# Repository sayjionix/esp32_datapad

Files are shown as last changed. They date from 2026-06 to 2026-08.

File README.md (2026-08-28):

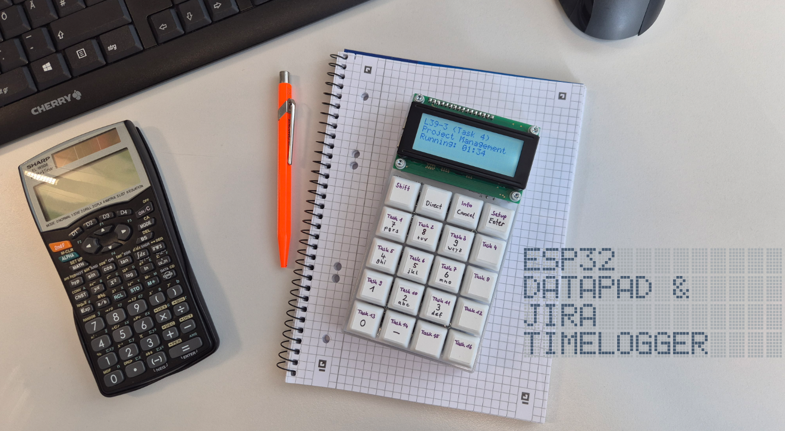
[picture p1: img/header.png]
Header


# ESP32 Datapad & Jira Timelogger Introduction
The __ESP32 Datapad & Jira Timelogger__ is a handheld ESP32-based keypad with 20 keys, a 20x4 character LCD display and a provision for operating from a single 3,7V LiPo cell. While the __Datapad__ hardware can generally be used for multiple purposes and provides a universal hardware development platform, the __timelogger__ firmware specifically allows tracking and logging time to [__Jira__](https://www.atlassian.com/software/jira).

The main features are:
* Connect the Datapad with your Atlassian Jira account using the REST API
* Map up to 16 favorite Jira tasks to the physical keys of the Datapad
* Tap a key once to start logging your time, tap again to stop logging and transfer the time to Jira
* Seamlessly switch over from logging on one task to another
* Manually enter spent time to book to your task
* Supports configuration of 2 WiFis to use the Datapad at two locations, e.g. at home and at workplace
* NTP-based time synchronization
* Use the Datapad as a development platform for your own keypad projects

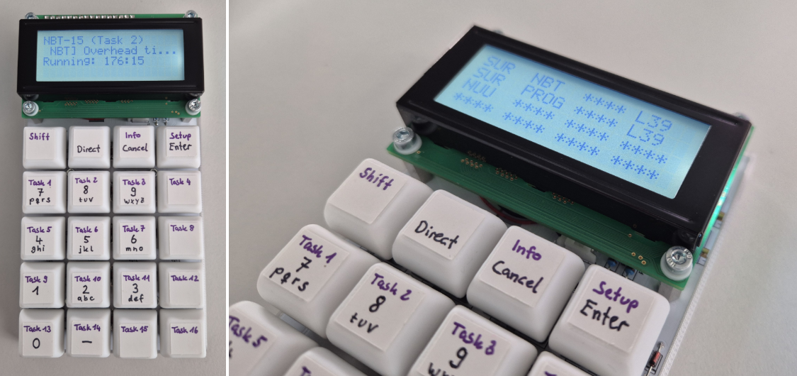
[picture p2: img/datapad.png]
datapad


# Build Instructions
Build your own Datapad! It's fun! :)

## BOM
The following table provides a BOM with Mouser and Reichelt part numbers.

| Part | Pcs | Type / Value | Mouser PN | Reichelt PN |
|---|:---:|---|---|---|
| | 1 | LCD Display 20x4 | 763-0420AZFSWGBW33V3 | |
| | 1 | Olimex ESP32-S3-DevKit-Lipo | 909-ESP32S3DEVKITLIP | |
| SW1-SW20 | 20  | Cherry MX Switch | 540-MX2A-E1NW | CHERRY MX2A-E1NW |
| D1-D20 | 20  | Diode 1N4148 | 512-1N4148 | 1N 4148 |
| Q1 | 1 | Transistor NPN BC548 | 637-BC548B | BC 548C |
| RV1 | 1 | Trim Poti 10k flat | | 64P-10K |
| RV2 | 1 | Trim Poti 2k flat | | 64P-2,0K |
| J1 | 1 | JST PH2P Socket | | JST PH2P ST90 |
| J2 | 1 | Pin Socket 1x16, 2,54mm, THT | 855-M20-7821646 | |
| | 1 | Pin Header 1x16, 2,54mm, THT | | |
| | 2 | Pin Header 1x22, 2,54mm, THT | | |
| R3 | 1 | Resistor 1/4W, 27k | | |
| R4 | 1 | Resistor 1/4W, 0R | | |
| SW21 | 1 | On-Off Switch | 611-OS102011MA1QN1 | |
| | 1 | LiPo Battery 3,7V, >= 100mAh | | |
| | 4 | 11mm Hexagonal Spacer or similar | | |

## Ordering and populating the PCB
The PCB can be ordered at any PCB manufacturer, such as [JLCPCB](https://jlcpcb.com/) or [PCBWay](https://www.pcbway.com/). In the [pcb/Datapad/fab/](pcb/Datapad/fab/) directory, there is a ZIP file with the Gerber and drill files, that can be used as-is to upload it to the manufacturer. For most manufacturers, you can likely leave all order options with their default values.

Soldering the components to the PCB should be simple, as the project only uses through-hole components. A generic tip is, to start with the small and flat parts first, such as the diodes and resistors, and then progress with the more bulky parts, such as the Cherry MX switches.

Solder the two 1x22 pin headers to the bottom of the Olimex ESP32 board and solder the 1x16 pin header to the bottom of the LCD display.

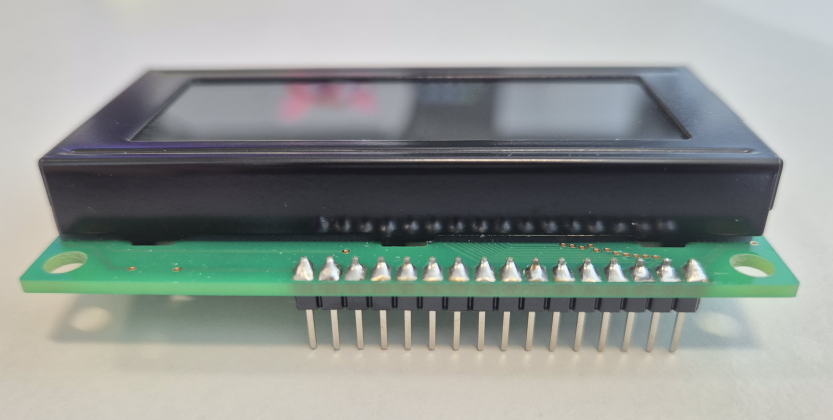
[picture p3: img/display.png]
display


It is recommended to solder the ESP32 with the attached pin headers to the main PCB as flush as possible to have enough clearance for the LCD display. Also, solder the ESP32 to the main PCB as one of the last steps. This way, you don't "lose" the ESP32 board in case any other step of the soldering goes wrong.

To power the ESP32 board from battery, solder a cable between the JST connector on the board and the Datapad PCB. Attach the battery with it's connector to the socket on the Datapad PCB.

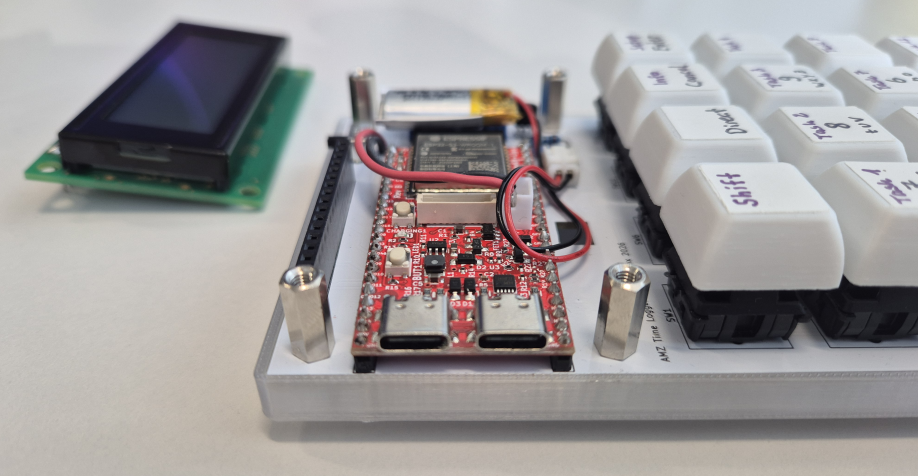
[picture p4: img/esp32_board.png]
esp32_board


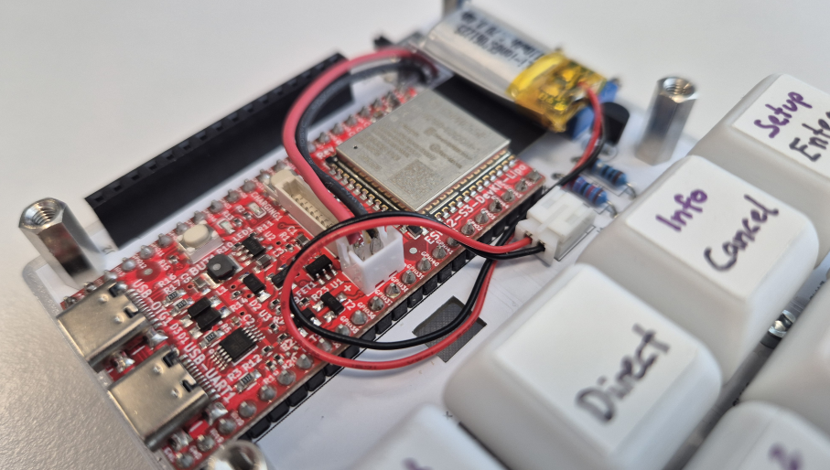
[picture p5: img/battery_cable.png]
battery_cable


## Programming the ESP32
This project is built and optimized using the PlatformIO ecosystem.

1. Download and install [VS Code](https://code.visualstudio.com/).
2. Install the PlatformIO IDE module directly from the VS Code Extensions Marketplace.
3. Connect the ESP32 board up to your PC with the right-side USB-C connector (when looking to the front of the USB ports. Labeled "USB-UART1").
4. Access the PlatformIO sidebar menu (represented by the Ant icon on the left panel grid) and open the timelogger project in the folder that contains the _platformio.ini_
5. Click the "Upload" action button (represented by the right-facing horizontal arrow icon along the bottom window status bar).
6. Wait for the code to be compiled and uploaded to the ESP32 via it's serial bootloader.

## 3D-printed Parts
There are *.stl files available in the [mechanical/](mechanical/) directory for two different variants of housings.

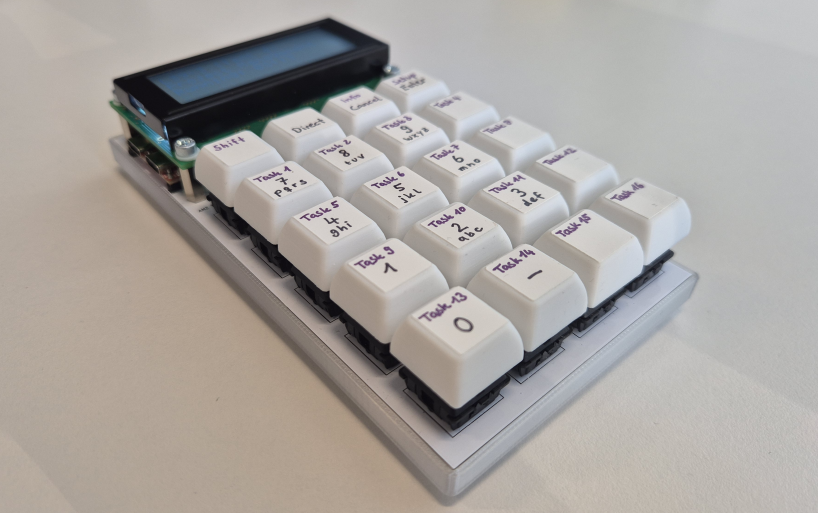
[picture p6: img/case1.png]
case1


For the Cherry MX Keycaps, the following free online model is recommended. However, any Cherry MX compatible keycaps can be used.<br>
https://makerworld.com/de/models/132469-xda-style-keycaps-blank#profileId-143606

# Operating Manual
## Keypad Layout
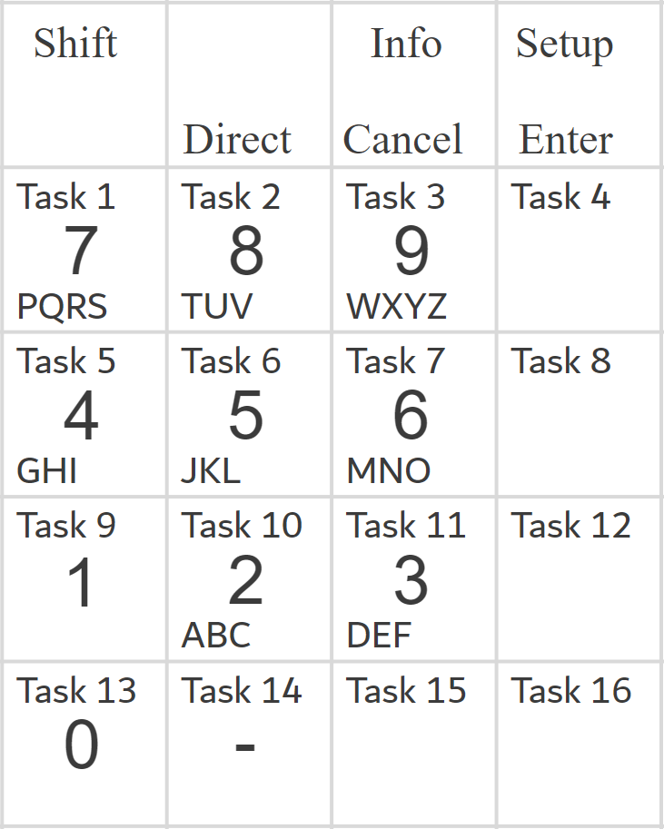
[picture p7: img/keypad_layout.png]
keypad_layout


## Energy Saving
After 60 seconds of inactivity, the Datapad will turn off the LCD display and backlight and it will bring the ESP32 into light sleep mode. Any running timers will keep on running in the background. To wake the Datapad up again, simply press any key on the keypad. This keypress will not trigger any action other than waking up.

## Display settings
Use the two potentiometers to adjust display contrast and backlight intensity.

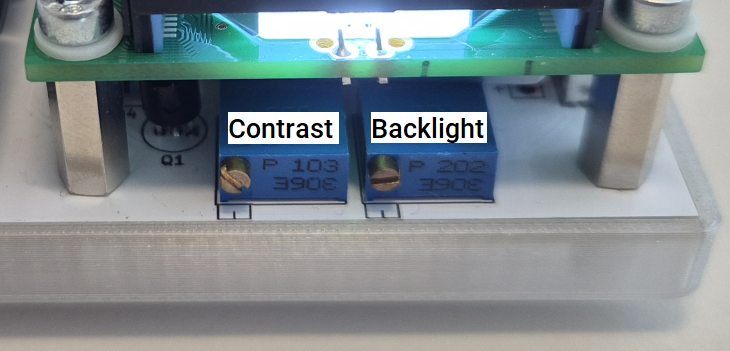
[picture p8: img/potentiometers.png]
potentiometers


## Battery operation
The On/Off switch on the top of the Datapad connects/disconnects the battery from the circuit. That means:

* to charge the battery from USB, make sure the On/Off switch is set to "On".
* the Datapad will be powered independently of the On/Off switch, once any of the two USB-C ports is connected to a power source.

## Base configuration
The basic configuration of the Datapad is performed via a serial terminal connection to your PC. You can use the same USB-C connection that you used for programming the ESP32 board and either utilize PlatformIO's Serial Monitor feature or any other serial terminal program of your choice. The serial setting are 115200baud, 8N1.

The basic configuration via the serial terminal includes:
1. WiFi 1 Name (SSID)
2. WiFi 1 Password
3. WiFi 2 Name (SSID)
4. WiFi 2 Password
5. Jira-Host
6. Base64 Credentials
7. Max Timer Duration

If the Datapad is started the first time and there is no configuration yet, it will prompt you to connect to your PC. The firmware can not start without the basic setup and having at least WiFi 1 configured and the Jira-Host and the Base64 Credentials set.

You can re-enter the basic configuration again at any time by pressing and holding the _SHIFT_ key + _ENTER_ key, while turning on the Datapad.

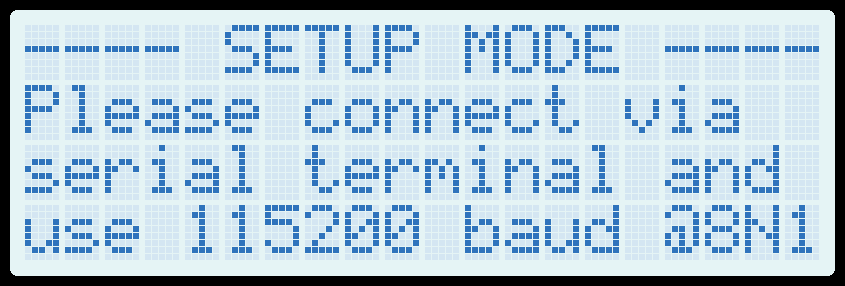
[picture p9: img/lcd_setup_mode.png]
lcd_setup_mode


Troubleshooting: If you don't see any output in the terminal, try sending anything (except a number between 1-8) to the Datapad. The firmware will reject this as an invalid choice for the main menu and re-render the main menu.

### Create your base64 credentials from your Jira API Token
A base64 representation of your Jira API token is required to access Jira's REST API. To get this, you have to perform the following steps:

1. Generate an API token for Jira using your Atlassian Account. Go to your account settings -> Security -> API Token.
2. Build a string of the form useremail:api_token.
3. BASE64 encode the string.

   Linux/Unix/MacOS:
   ```
   echo -n "user@example.com:api_token_string" | base64
   ```

   Windows 7 and later, using Microsoft Powershell:
   ```
   $Text = ‘user@example.com:api_token_string’
   $Bytes = [System.Text.Encoding]::UTF8.GetBytes($Text)
   $EncodedText = [Convert]::ToBase64String($Bytes)
   $EncodedText
   ```
4. Make sure that your resulting base64 string doesn't contain any unwanted carriage returns or other whitespace characters when you copy them to your Datapad configuration via the terminal. Unwanted whitespace characters are a common reason why the Jira login does not work later on. It can be easily checked by pasting the resulting base64 string into a text editor that can show whitespace characters, such as notepad++.

## Jira task mapping
If the Datapad starts with a valid configuration, it will show a 4x4 matrix of your 16 favorite Jira IDs on the LCD display (each Jira ID is consisting of the alphanumeric Jira key, followed by an unique number, e.g. "MGMT-2"). This 4x4 matrix corresponds to the lower 4x4 segment of the physical keypad.

If no Jira IDs have been mapped yet, each cell of the matrix will show "****".<br>
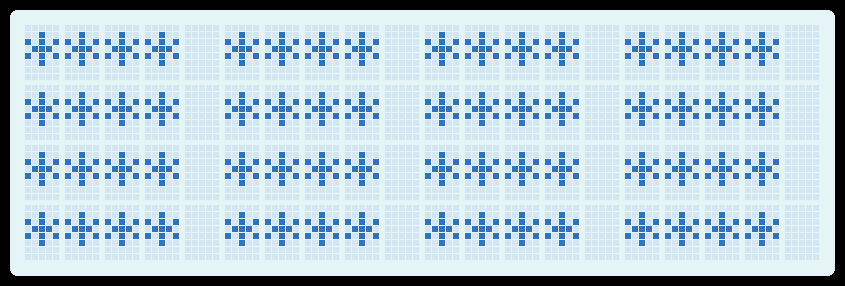
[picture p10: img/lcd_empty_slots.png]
lcd_empty_slots


Once Jira IDs have been mapped to the 4x4 matrix, the Datapad will periodically cycle through indicating the Jira key and the unique identifier at the given cell on the LCD display.<br>
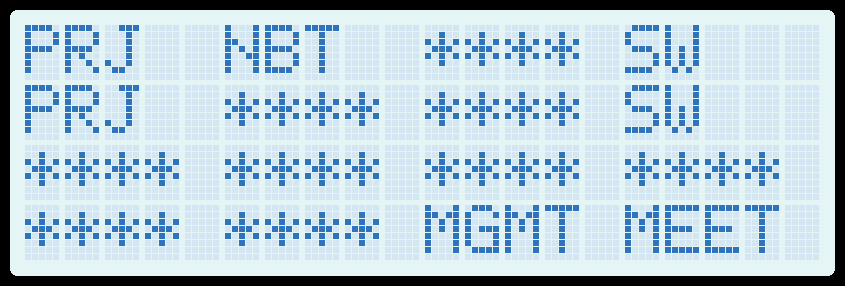
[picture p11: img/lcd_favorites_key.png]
lcd_favorites_key

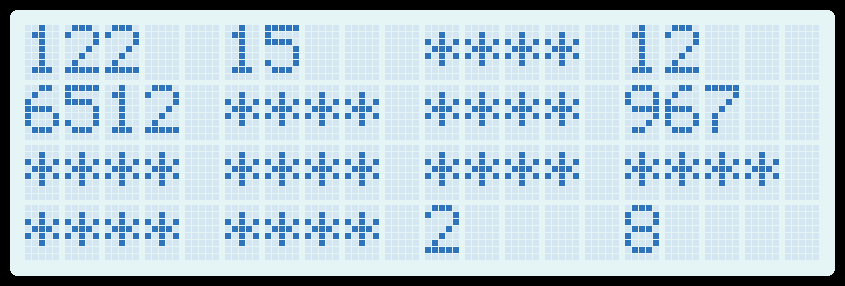
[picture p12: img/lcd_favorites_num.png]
lcd_favorites_num


### Map a Jira task ID to a physical key
To map a new Jira task to any of the free slots of your 4x4 matrix of favorites, simply press and hold the _SHIFT_ key and then press the key that corresponds to the slot you like to map. A dialog will show on the LCD display that prompts you for the Jira ID. The Jira ID can be entered using the T9-feature of the keypad. Each Jira ID is consisting of the alphanumeric Jira key, followed by an unique number, e.g. "MGMT-2".

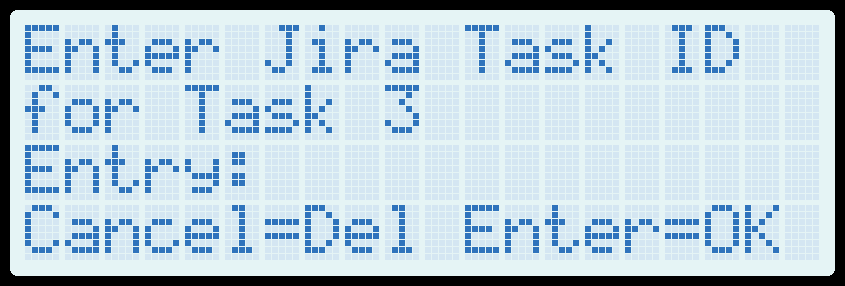
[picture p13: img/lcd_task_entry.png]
lcd_task_entry


To correct a typing mistake or to exit the dialog completely, simply press _CANCEL_ (repeatedly).
To conclude your entry and map the Jira ID, press _ENTER_. The Datapad will call the REST API to fetch information about the task, such as the task's name. If the task can not be found or there is any other issue with the connection to your Jira server, the mapping will be completed, calling the task "Unknown Task". 

### Remove a Jira task ID from a physical key
To remove a Jira task from the 4x4 matrix of favorites, simply press and hold the _CANCEL_ key before pressing the key of the task you like to remove. A confirmation dialoge will prompt you to either continue by pressing _ENTER_, or to cancel the removal by pressing _CANCEL_.

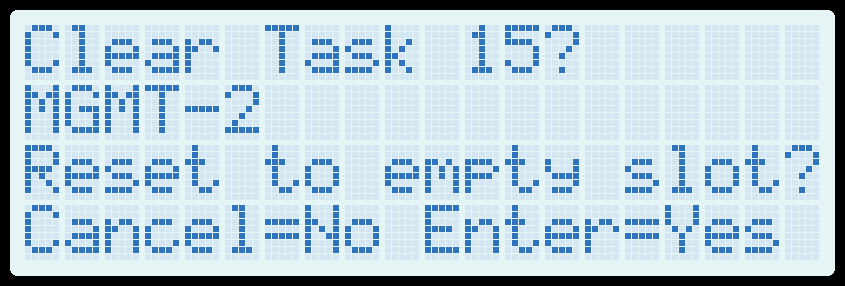
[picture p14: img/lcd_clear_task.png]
lcd_clear_task


Once the Jira task is removed, the slot becomes free again and is displayed as "****".

### Show task name
When mapping a Jira task to one of the slots of the 4x4 matrix, the Datapad will try to obtain the task's name via the Jira REST API. To display the name of a task in your 4x4 matrix, simply press and hold the _ENTER_ key before pressing the key of the task you like to show. This can be helpful when you are unsure to recognize the right task just judging from the Jira ID.

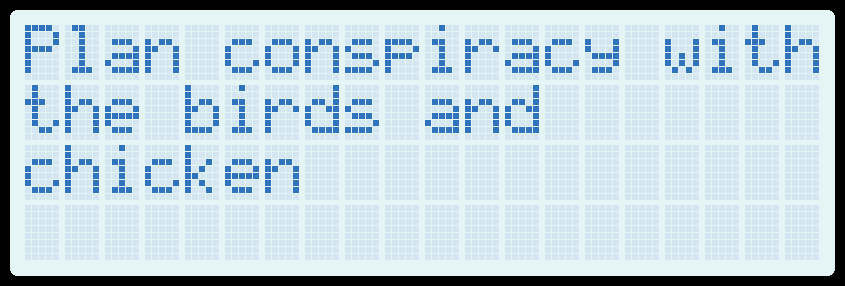
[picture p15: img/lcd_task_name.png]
lcd_task_name


## Log time
There are two ways to log time to your Jira tasks.

### Automatic timer mode
A worklog timer can be started for any of the Jira tasks from the 4x4 matrix of favorites by simply pressing the key that corresponds to the task you like to log. Once the timer has started, the LCD display switches to an indication of the running timer. To stop a running timer, press the according task key again. A dialog will prompt you to confirm whether you would like to log the recorded timer to Jira. Press the _ENTER_ key once you are ready to log the time. The Datapad will then transmit the time to Jira via the REST API and automatically calculate the starting time of the activity based on the recorded minutes. Press _CANCEL_ to discard the recorded time.

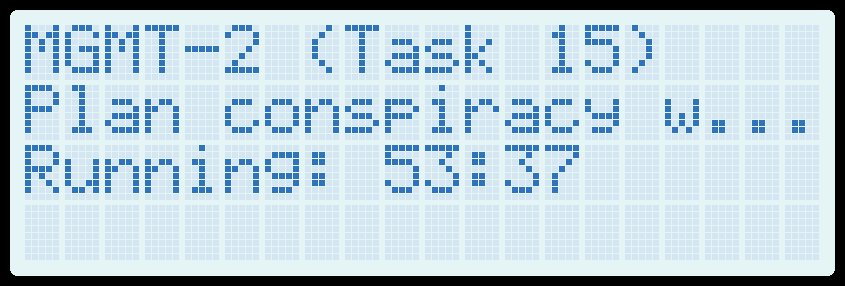
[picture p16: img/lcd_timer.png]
lcd_timer


If you start a timer in parallel on a different Jira task, the Datapad will automatically stop the previously running timer and prompt you, whether to keep or discard the recording of the previous timer. It will then start the new timer.

Timers can only be started on non-empty slots.

### Direct entry
Time can also be entered directly to be logged to a certain Jira task. This is helpful if you forgot to start the timer before you started working on your activity and you would like to restrospecively log the time.

Press and hold _DIRECT_ and then press the key that corresponds to the task you like to log to. A dialog will prompt you to enter the time in minutes using the numeric keys. Press the _CANCEL_ key to correct your entry or to completely cancel the direct time entry. Press the _ENTER_ key once you are ready to log the time. The Datapad will then transmit the time to Jira via the REST API and automatically calculate the starting time of the activity based on the entered minutes.

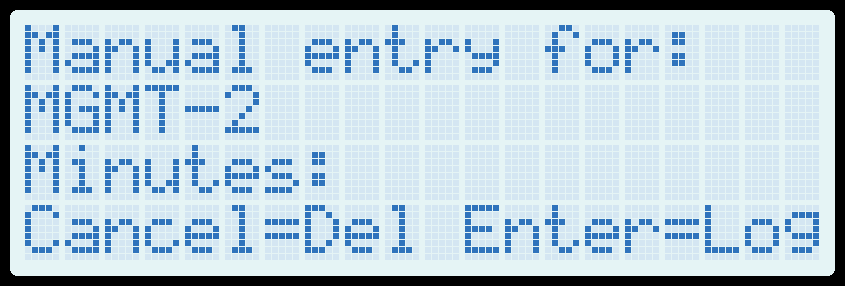
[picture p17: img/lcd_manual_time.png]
lcd_manual_time


## Information Display
When pressing the _SHIFT_ and _INFO_ keys simultaneously while being in the 4x4 overview, the LCD display will show:
* Firmware version
* Battery voltage (when running from battery) or "USB connected" (when being powered from USB)
* Actual time and date. Time and date will be fetched via NTP every 3 hours. This is to compensate for the poor crystal accuracy of the ESP32 board and the clock drift that comes as a result

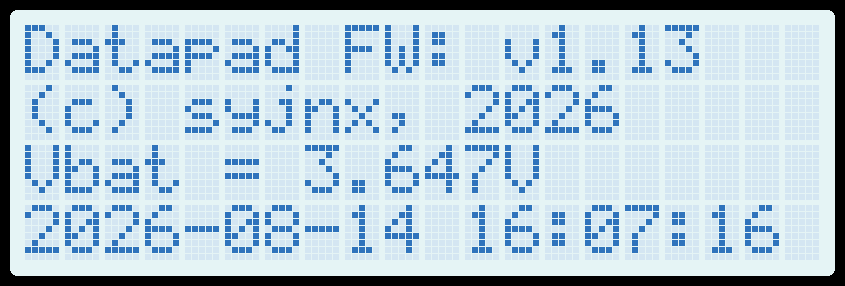
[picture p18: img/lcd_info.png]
lcd_info


Press _CANCEL_ or _ENTER_ to return.

# Hardware Changelog
**v1.0, 31.05.2026:** First fab release of PCB.

# License
The Datapad Timelogger is released under the GNU GPLv3.<br>
Please refer to the [LICENSE](./LICENSE) file for more information.

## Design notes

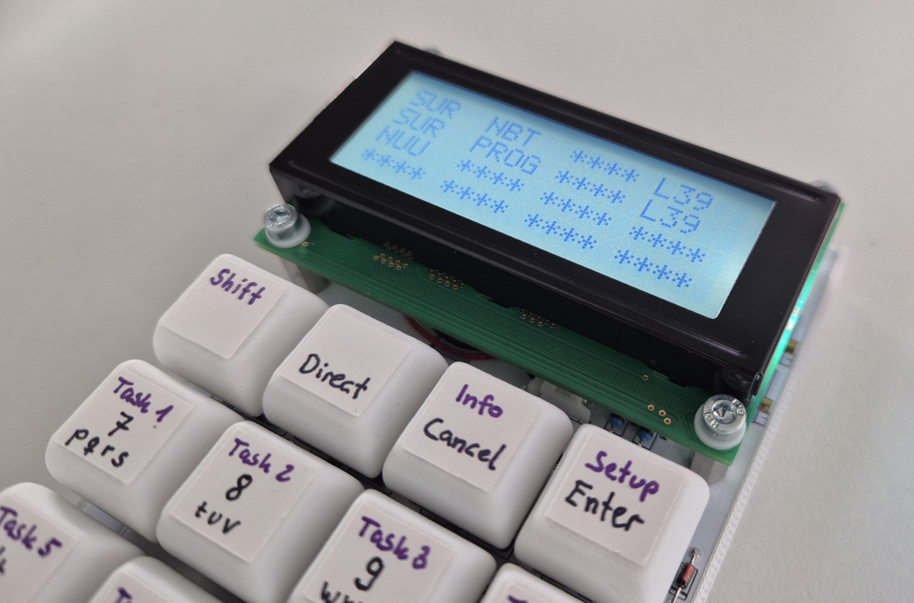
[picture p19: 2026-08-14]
img/datapad_2.png

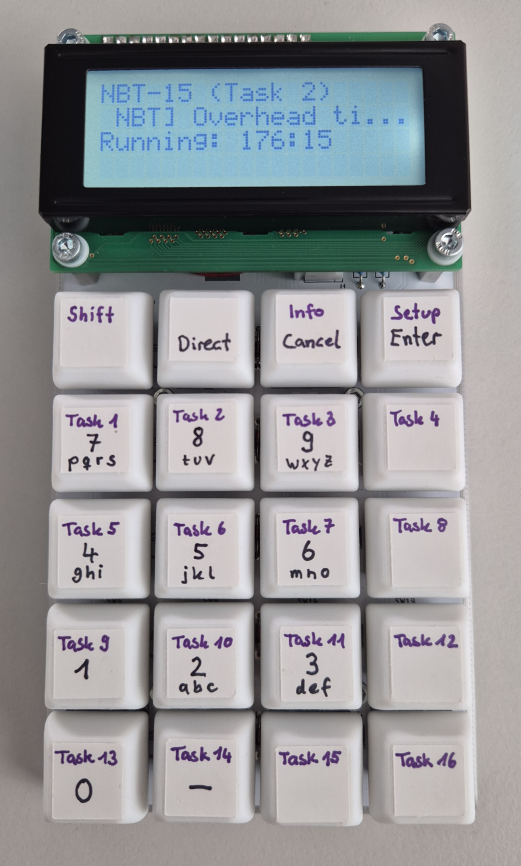
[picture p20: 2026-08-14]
img/datapad_1.png

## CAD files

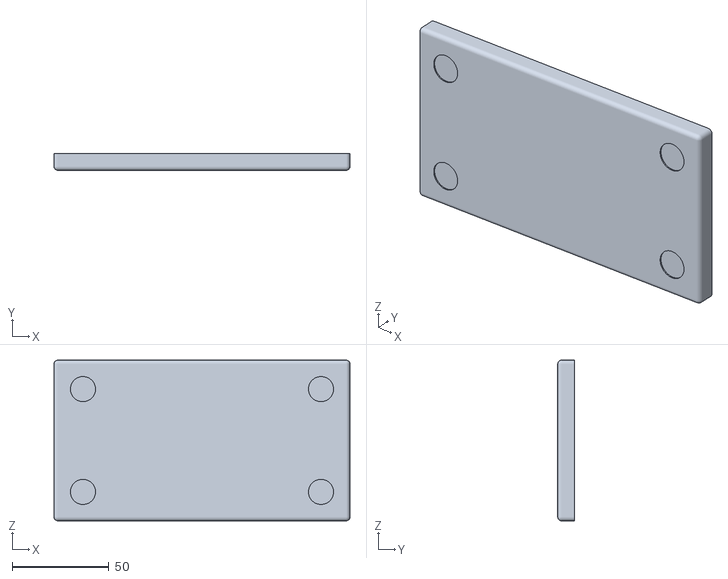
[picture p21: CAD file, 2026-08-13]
mechanical/Datapad_Case_v2.stl
153.2 x 8.60 x 83.2

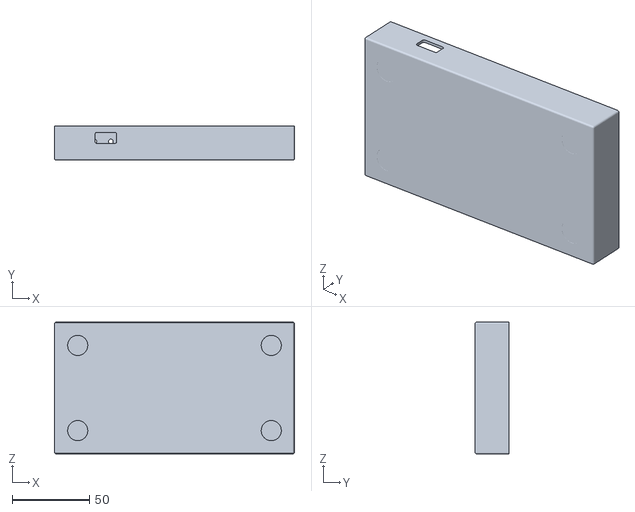
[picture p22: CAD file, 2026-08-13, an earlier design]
mechanical/Datapad_Case_v1.stl
155.0 x 22.0 x 85.0

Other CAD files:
mechanical/Datapad_Case_v1.ipt
mechanical/Datapad_Case_v2.ipt

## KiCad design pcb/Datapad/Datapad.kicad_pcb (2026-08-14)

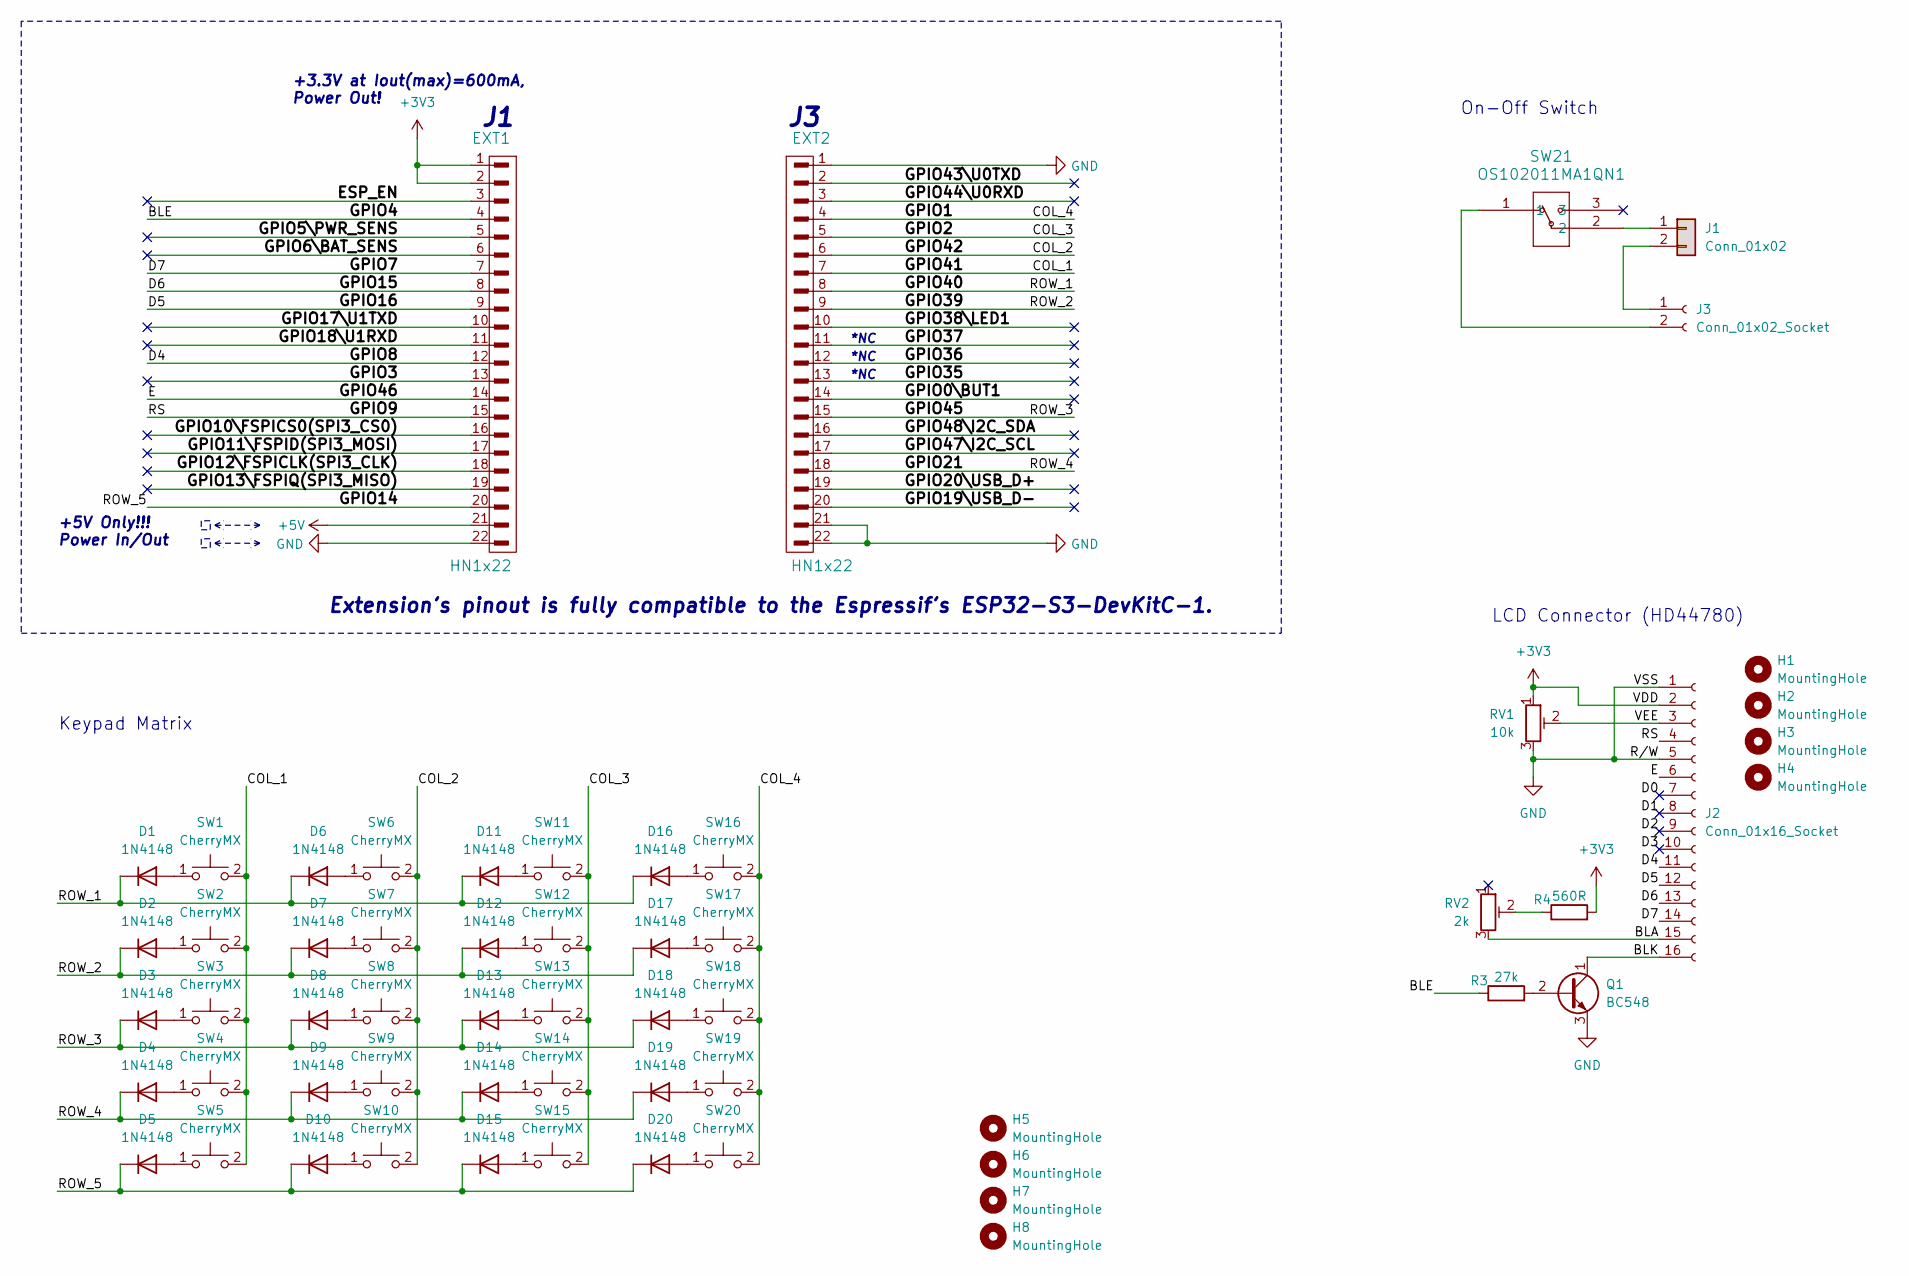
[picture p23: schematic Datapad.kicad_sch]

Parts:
D1, D2, D3, D4, D5, D6, D7, D8, D9, D10, D11, D12, D13, D14, D15, D16, D17, D18, D19, D20: 1N4148; D_DO-35_SOD27_P7.62mm_Horizontal
EXT1, EXT2: HN1x22; PinSocket_1x22_P2.54mm_Vertical
H1, H2, H3, H4: MountingHole; MountingHole_4mm
H5, H6, H7, H8: MountingHole; MountingHole_2.7mm
J1: Conn_01x02; JST_PH_S2B-PH-K_1x02_P2.00mm_Horizontal
J2: Conn_01x16_Socket; PinSocket_1x16_P2.54mm_Vertical
J3: Conn_01x02_Socket; PinSocket_1x02_P2.54mm_Vertical
Q1: BC548; TO-92_Inline
R3: 27k; R_Axial_DIN0207_L6.3mm_D2.5mm_P10.16mm_Horizontal
R4: 560R; R_Axial_DIN0207_L6.3mm_D2.5mm_P10.16mm_Horizontal
RV1: 10k; Potentiometer_Bourns_3296P_Horizontal
RV2: 2k; Potentiometer_Bourns_3296P_Horizontal
SW1, SW2, SW3, SW4, SW5, SW6, SW7, SW8, SW9, SW10, SW11, SW12, SW13, SW14, SW15, SW16, SW17, SW18, SW19, SW20: CherryMX; SW_Cherry_MX_1.00u_PCB
SW21: OS102011MA1QN1; OS102011MA1QN1_CNK

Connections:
+3V3: EXT1.1, EXT1.2, J2.2, R4.2, RV1.1
+5V: EXT1.21
/BLA: J2.15, RV2.3
/BLE: EXT1.4, R3.1
/BLK: J2.16, Q1.1 (C)
/COL_1: EXT2.7, SW1.2, SW2.2, SW3.2, SW4.2, SW5.2
/COL_2: EXT2.6, SW6.2, SW7.2, SW8.2, SW9.2, SW10.2
/COL_3: EXT2.5, SW11.2, SW12.2, SW13.2, SW14.2, SW15.2
/COL_4: EXT2.4, SW16.2, SW17.2, SW18.2, SW19.2, SW20.2
/D0: J2.7
/D1: J2.8
/D2: J2.9
/D3: J2.10
/D4: EXT1.12, J2.11
/D5: EXT1.9, J2.12
/D6: EXT1.8, J2.13
/D7: EXT1.7, J2.14
/E: EXT1.14, J2.6
/ESP_EN: EXT1.3
/GPIO0\BUT1: EXT2.14
/GPIO3: EXT1.13
/GPIO5\PWR_SENS: EXT1.5
/GPIO6\BAT_SENS: EXT1.6
/GPIO9: EXT1.15, J2.4
/GPIO10\FSPICS0(SPI3_CS0): EXT1.16
/GPIO11\FSPID(SPI3_MOSI): EXT1.17
/GPIO12\FSPICLK(SPI3_CLK): EXT1.18
/GPIO13\FSPIQ(SPI3_MISO): EXT1.19
/GPIO14: D5.1 (K), D10.1 (K), D15.1 (K), D20.1 (K), EXT1.20
/GPIO17\U1TXD: EXT1.10
/GPIO18\U1RXD: EXT1.11
/GPIO19\USB_D-: EXT2.20
/GPIO20\USB_D+: EXT2.19
/GPIO21: D4.1 (K), D9.1 (K), D14.1 (K), D19.1 (K), EXT2.18
/GPIO35: EXT2.13
/GPIO36: EXT2.12
/GPIO37: EXT2.11
/GPIO38\LED1: EXT2.10
/GPIO39: D2.1 (K), D7.1 (K), D12.1 (K), D17.1 (K), EXT2.9
/GPIO40: D1.1 (K), D6.1 (K), D11.1 (K), D16.1 (K), EXT2.8
/GPIO43\U0TXD: EXT2.2
/GPIO44\U0RXD: EXT2.3
/GPIO45: D3.1 (K), D8.1 (K), D13.1 (K), D18.1 (K), EXT2.15
/GPIO47\I2C_SCL: EXT2.17
/GPIO48\I2C_SDA: EXT2.16
/VEE: J2.3, RV1.2
GND: EXT1.22, EXT2.1, EXT2.21, EXT2.22, J2.1, J2.5, Q1.3 (E), RV1.3
unnamed: D1.2 (A), SW1.1
unnamed: D2.2 (A), SW2.1
unnamed: D3.2 (A), SW3.1
unnamed: D4.2 (A), SW4.1
unnamed: D5.2 (A), SW5.1
unnamed: D6.2 (A), SW6.1
unnamed: D7.2 (A), SW7.1
unnamed: D8.2 (A), SW8.1
unnamed: D9.2 (A), SW9.1
unnamed: D10.2 (A), SW10.1
unnamed: D11.2 (A), SW11.1
unnamed: D12.2 (A), SW12.1
unnamed: D13.2 (A), SW13.1
unnamed: D14.2 (A), SW14.1
unnamed: D15.2 (A), SW15.1
unnamed: D16.2 (A), SW16.1
unnamed: D17.2 (A), SW17.1
unnamed: D18.2 (A), SW18.1
unnamed: D19.2 (A), SW19.1
unnamed: D20.2 (A), SW20.1
unnamed: J1.1, SW21.2
unnamed: J1.2, J3.1
unnamed: J3.2, SW21.1
unnamed: Q1.2 (B), R3.2
unnamed: R4.1, RV2.2

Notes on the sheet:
+5V Only!!! Power In/Out
Keypad Matrix
+3.3V at Iout(max)=600mA, Power Out!
Extension's pinout is fully compatible to the Espressif's ESP32-S3-DevKitC-1.
*NC
On-Off Switch
LCD Connector (HD44780)

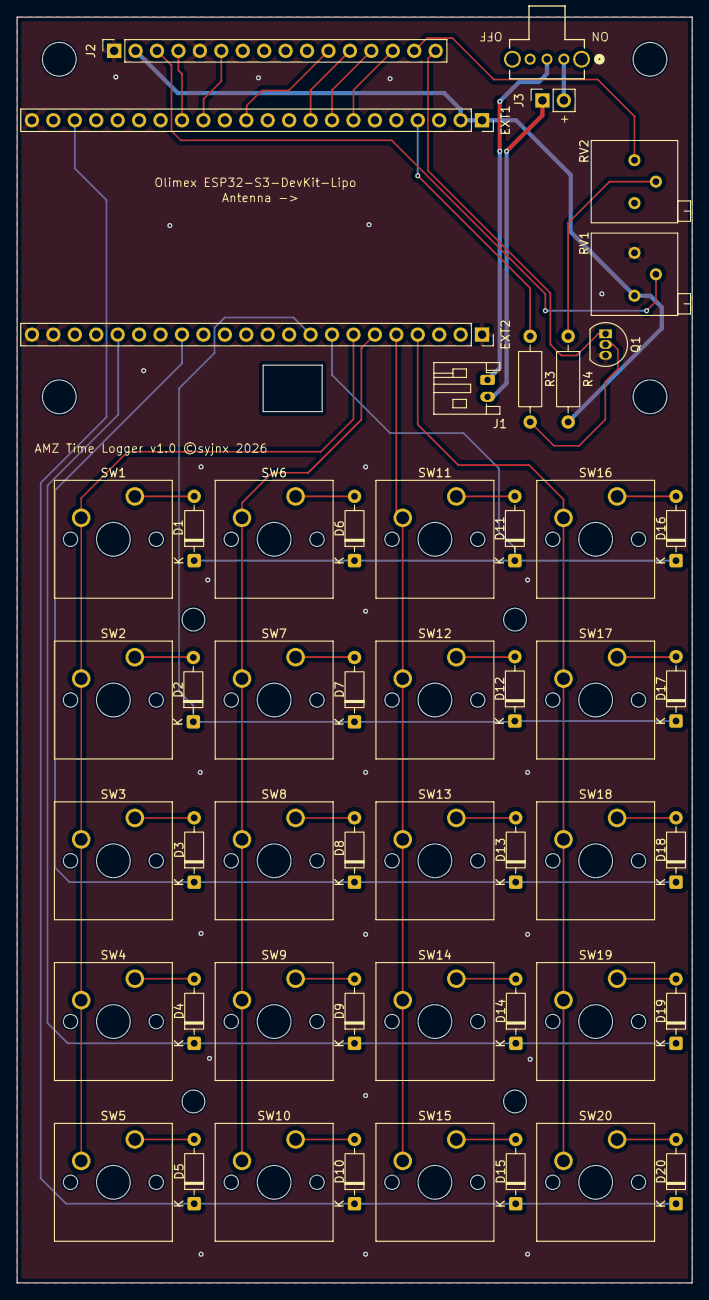
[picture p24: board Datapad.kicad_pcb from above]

Board: 2 copper layers, 80.0 x 150.0 mm, 59 parts (0 on the bottom side), 46 nets.

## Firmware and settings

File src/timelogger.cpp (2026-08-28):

/**************************************************************************************************/
/** @file      timelogger.cpp
 *  @copyright (C) 2026, sayjionix (syjnx), All Rights Reserved
 *             https://github.com/sayjionix/esp32_datapad
 *  @brief     Main program file of Jira timelogger firmware for the ESP32 Datapad
 *  @date      13.08.2026
 */
/**************************************************************************************************/

/*** Component includes ***/
/**************************************************************************************************/
#include <WiFi.h>
#include <HTTPClient.h>
#include <WiFiClientSecure.h>
#include <Keypad.h>
#include <Preferences.h>
#include <LiquidCrystal.h>
#include <ArduinoJson.h>
#include <time.h>

/*** Component local macro definitions ***/
/**************************************************************************************************/
// HD44780 LCD Pins: LiquidCrystal lcd(rs, en, d4, d5, d6, d7)
LiquidCrystal lcd(9, 46, 8, 16, 15, 7);
#define BACKLIGHT_PIN  4    // GPIO4
#define BAT_ADC_PIN    6    // GPIO6 (Battery)
#define PWR_ADC_PIN    5    // GPIO5 (External power)

#define ADC_RESOLUTION 4095.0
#define ADC_REF        3.3

// Correct ratios from schematic
#define BAT_DIVIDER_RATIO  4.1333
#define PWR_DIVIDER_RATIO  5.6808

// 5V through divider gives ~880mV at ADC, anything above 400mV means external power present
#define PWR_PRESENT_THRESHOLD 400

/*** Component local type declarations ***/
/**************************************************************************************************/

/*** Component exported data definitions ***/
/**************************************************************************************************/

/*** Component local data definitions ***/
/**************************************************************************************************/
Preferences preferences;
String VERSION = "v1.15";

// WiFi and Jira configuration variables
String ssid = "";
String password = "";
String ssid2 = "";
String password2 = "";
String jiraHost = ""; 
String base64Credentials = ""; 
unsigned long maxTimerHours = 10; // Default maximum tracking duration in hours

unsigned long lastActivityTime = 0;
const unsigned long displayTimeout = 60000; 
bool isDisplayOn = true;
bool displayNameToggle = true;
bool isShowingInfoPage = false; // Flag to block UI drawing while showing version info

// Variables for Task Name Inspector Feature
bool isShowingTaskInspector = false;
unsigned long taskInspectorStartTime = 0;
const unsigned long taskInspectorTimeout = 2000; // 2 seconds

unsigned long lastNTPSyncTime = 0;
const unsigned long ntpSyncInterval = 10800000; // 3 hours in milliseconds

// Keypad Definition (rows and cols are inverted here to match anti-ghosting diode polarity with library code)
const byte ROWS = 4; 
const byte COLS = 5; 
char hexaKeys[ROWS][COLS] = {
  {'S','7','4','1','0'},
  {'A','8','5','2','G'},
  {'B','9','6','3','H'},
  {'C','D','E','F','I'}
};
byte rowPins[ROWS] = {41, 42, 2, 1}; 
byte colPins[COLS] = {40, 39, 45, 21, 14};
int keyTaskMap[ROWS][COLS] = {
  {-1,0,4,8,12},
  {-1,1,5,9,13},
  {-1,2,6,10,14},
  {-1,3,7,11,15}
};

Keypad customKeypad = Keypad(makeKeymap(hexaKeys), rowPins, colPins, ROWS, COLS);

String taskMapping[20];
String taskNames[20];
unsigned long startTimes[20] = {0};
int activeTimerIndex = -1;

int configIndex = -1;
int manualTimeIndex = -1;
int confirmTrackingIndex = -1;
unsigned long confirmDurationMinutes = 0;
int nextTimerIndexToStart = -1;

// Variables for slot deletion
int deleteIndex = -1;
bool isShowingDeleteDialog = false;

String currentInput = "";
char lastT9Key = '\0';
int t9CycleIndex = 0;
unsigned long lastT9Time = 0;
const unsigned long t9Timeout = 1200;

const String t9Chars[11] = {
  "1", "ABC2", "DEF3", "GHI4", "JKL5", "MNO6", "PQRS7", "TUV8", "WXYZ9", "0", "-"
};

/*** Component local function declarations ***/
/**************************************************************************************************/
void resetDisplayTimeout();
void updateDefaultDisplay();
String readSerialLine();
void runSerialSetup();
String fetchTaskSummary(String issueKey);
void handleManualTimeInput(char key);
void handleT9Input(char key);
void handleTracking(int index);
void handleConfirmationInput(char key);
void handleDeletionInput(char key);
void logTimeToJira(const char* issueKey, unsigned long minutes);
void enterLowPowerMode();
bool connectToWiFiNetwork(String targetSsid, String targetPass, const char* label);
bool ensureWiFiConnected();
void showTaskNameMultiLine(String name);

// Read battery voltage
float readBatVoltage()
{
  uint32_t adcRaw = analogRead(BAT_ADC_PIN);

  float adcVoltage = (adcRaw / ADC_RESOLUTION) * ADC_REF;
  float realVoltage = adcVoltage * BAT_DIVIDER_RATIO;

  return realVoltage;
}

// Check for external power via USB
bool externalPowerPresent()
{
  uint32_t adcRaw = analogRead(PWR_ADC_PIN);
  float adcVoltage = (adcRaw / ADC_RESOLUTION) * ADC_REF;
  return (((uint16_t)(adcVoltage * 1000.0)) > PWR_PRESENT_THRESHOLD);
}

// Return the index of the keypad's key-to-task mapping
int getKeyIndex(char key)
{
  for (int i = 0; i < ROWS; i++) {
    for (int j = 0; j < COLS; j++) {
      if (hexaKeys[i][j] == key) {
        return keyTaskMap[i][j];
      }
    }
  }
  return -1;
}

// Map keypad keys to T9 layout indices
int getT9LayoutIndex(char key)
{
  if (key >= '1' && key <= '9') return key - '1';
  if (key == '0') return 9;
  if (key == 'G') return 10;
  return -1;
}

// Reset display sleep timer
void resetDisplayTimeout()
{
  lastActivityTime = millis();
}

// Splits and draws a string across 4 rows on the LCD
void showTaskNameMultiLine(String name)
{
  lcd.clear();
  int startIdx = 0;
  for (int row = 0; row < 4; row++) {
    if (startIdx >= name.length()) break;
    
    String line = name.substring(startIdx, startIdx + 20);
    
    // Simple word wrapping helper logic if within boundary limits
    if (startIdx + 20 < name.length() && line.lastIndexOf(' ') > 10) {
      int lastSpace = line.lastIndexOf(' ');
      line = line.substring(0, lastSpace);
      startIdx += lastSpace + 1;
    } else {
      startIdx += 20;
    }
    
    lcd.setCursor(0, row);
    lcd.print(line);
  }
}

// Render the current UI state to the LCD
void updateDefaultDisplay()
{
  // Block redraw requests if user is interacting with modal sub-pages or dialogs
  if (isShowingInfoPage || isShowingDeleteDialog || isShowingTaskInspector) return;

  lcd.clear();
  
  // There is an active timer running
  if(activeTimerIndex != -1)
  {
    // Show real task name (if available) and associated key
    lcd.setCursor(0, 0);
    String displayName = taskMapping[activeTimerIndex] + " (Task " + (activeTimerIndex+1) + ")";
    lcd.print(displayName);
    lcd.setCursor(0, 1);
    displayName = taskNames[activeTimerIndex];
    if (displayName.length() > 20) displayName = displayName.substring(0, 17) + "...";
    lcd.print(displayName);
  }
  // No active timer running -> show Jira ID overview matrix
  else
  {
    for(int line=0; line < 4; line++) {
      for (int j=0; j < 4; j++) {
        lcd.setCursor(j*5, line);
        String displayName = taskMapping[line*4+j];
        int dashidx = displayName.indexOf('-');

        // Toggle between Project Key and Issue Number display
        if(displayNameToggle) {
          displayName = displayName.substring(0, dashidx);
        }
        else {
          displayName = displayName.substring(dashidx+1, dashidx+7);
        }
        if (displayName.length() > 4) {
          displayName = displayName.substring(0, 4);
        }
        lcd.print(displayName);
      }
    }
  }
}

// Robustly read a line from serial interface filtering out both Carriage Return and Line Feed
String readSerialLine()
{
  String input = "";
  while (true) {
    if (Serial.available()) {
      char c = Serial.read();
      if (c == '\n' || c == '\r') {
        // If we hit a newline character and already have content, we finish reading
        if (input.length() > 0) {
          break;
        }
      } else {
        input += c;
      }
    }
    delay(5);
  }
  input.trim();
  return input;
}

// Interactive configuration wizard via hardware serial terminal
void runSerialSetup()
{
  lcd.clear();
  lcd.setCursor(0, 0); lcd.print("---- SETUP MODE ----");
  lcd.setCursor(0, 1); lcd.print("Please connect via  ");
  lcd.setCursor(0, 2); lcd.print("serial terminal and ");
  lcd.setCursor(0, 3); lcd.print("use 115200 baud @8N1");

  // Load existing values first so they are up to date in the menu
  ssid = preferences.getString("wifi_ssid", "");
  password = preferences.getString("wifi_pass", "");
  ssid2 = preferences.getString("wifi_ssid2", "");
  password2 = preferences.getString("wifi_pass2", "");
  jiraHost = preferences.getString("jira_host", "");
  base64Credentials = preferences.getString("jira_cred", "");
  maxTimerHours = preferences.getUInt("max_hours", 10);

  while (true) {
    Serial.println("\n==================================================");
    Serial.println("         CONFIGURATION OF TIME TRACKER            ");
    Serial.println("==================================================");
    Serial.print("1. WiFi 1 Name (SSID):       "); Serial.println(ssid == "" ? "[NOT SET]" : ssid);
    Serial.print("2. WiFi 1 Password:          "); Serial.println(password == "" ? "[NOT SET]" : "********");
    Serial.print("3. WiFi 2 Name (SSID):       "); Serial.println(ssid2 == "" ? "[NOT SET (OPTIONAL)]" : ssid2);
    Serial.print("4. WiFi 2 Password:          "); Serial.println(password2 == "" ? "[NOT SET]" : "********");
    Serial.print("5. Jira-Host:                "); Serial.println(jiraHost == "" ? "[NOT SET]" : jiraHost);
    Serial.print("6. Base64 Credentials:       "); Serial.println(base64Credentials == "" ? "[NOT SET]" : "[SAVED]");
    Serial.print("7. Max Timer Duration:       "); Serial.print(maxTimerHours); Serial.println(" Hours");
    Serial.println("--------------------------------------------------");
    Serial.println("8. Restart System");
    Serial.println("==================================================");
    Serial.print("Please select an option (1-8): ");

    String choice = readSerialLine();
    Serial.println(choice);

    if (choice == "1") {
      Serial.print("Enter new WiFi 1 Name (SSID): ");
      ssid = readSerialLine();
      Serial.println(ssid);
      preferences.putString("wifi_ssid", ssid);
      Serial.println("--> WiFi 1 Name updated in storage.");
    } 
    else if (choice == "2") {
      Serial.print("Enter new WiFi 1 Password: ");
      password = readSerialLine();
      Serial.println("********");
      preferences.putString("wifi_pass", password);
      Serial.println("--> WiFi 1 Password updated in storage.");
    } 
    else if (choice == "3") {
      Serial.print("Enter new WiFi 2 Name (SSID): ");
      ssid2 = readSerialLine();
      Serial.println(ssid2);
      preferences.putString("wifi_ssid2", ssid2);
      Serial.println("--> WiFi 2 Name updated in storage.");
    }
    else if (choice == "4") {
      Serial.print("Enter new WiFi 2 Password: ");
      password2 = readSerialLine();
      Serial.println("********");
      preferences.putString("wifi_pass2", password2);
      Serial.println("--> WiFi 2 Password updated in storage.");
    }
    else if (choice == "5") {
      Serial.print("Enter new Jira-Host (e.g. company.atlassian.net): ");
      jiraHost = readSerialLine();
      Serial.println(jiraHost);
      preferences.putString("jira_host", jiraHost);
      Serial.println("--> Jira-Host updated in storage.");
    } 
    else if (choice == "6") {
      Serial.print("Enter new Base64 Credentials: ");
      base64Credentials = readSerialLine();
      Serial.println("[SAVED]");
      preferences.putString("jira_cred", base64Credentials);
      Serial.println("--> Base64 Credentials updated in storage.");
    } 
    else if (choice == "7") {
      Serial.print("Enter max timer duration (in hours): ");
      String hrsInput = readSerialLine();
      long parsedHrs = hrsInput.toInt();
      if (parsedHrs > 0) {
        maxTimerHours = parsedHrs;
        Serial.print(maxTimerHours); Serial.println(" Hours");
        preferences.putUInt("max_hours", maxTimerHours);
        Serial.println("--> Max timer duration updated in storage.");
      } else {
        Serial.println("Invalid input! Must be a positive number.");
      }
    } 
    else if (choice == "8") {
      Serial.println("\n--> All settings successfully verified! Restarting system...");
      break;
    } 
    else {
      Serial.print("Invalid selection! You entered '"); Serial.print(choice); Serial.println("'. Please enter a number between 1 and 8.");
    }
    delay(500);
  }

  lcd.clear();
  lcd.setCursor(0, 1); lcd.print("Data saved!");
  lcd.setCursor(0, 2); lcd.print("Restarting system...");
  delay(2000);
  ESP.restart();
}
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
void loop()
{
  bool isShiftPressed = false;
  bool isAPressed = false;
  bool isCancelPressed = false;
  bool isEnterPressed = false;
  static unsigned long lastUpdateTime = 0;

  // Automatic background NTP resynchronization every 3 hours
  if (millis() - lastNTPSyncTime >= ntpSyncInterval) {
    // We actively check or restore the connection before attempting the sync
    if (ensureWiFiConnected()) {
      Serial.println("[NTP] Triggering background time resync...");
      configTzTime("CET-1CEST,M3.5.0,M10.5.0/3", "pool.ntp.org", "time.nist.gov");
      
      // Only update the timestamp if the sync actually had a chance to complete
      lastNTPSyncTime = millis();
      
      // Restore the UI screen view in case ensureWiFiConnected() printed status updates
      updateDefaultDisplay();
    } else {
      Serial.println("[NTP] Sync deferred: WiFi not ready yet. Retrying next loop execution.");
      // We purposefully DO NOT update lastNTPSyncTime here, so it tries again 
      // on the next loop() pass until the network is fully available.
    }
  }

  // Handle non-blocking timeout for Task Name Inspector view
  if (isShowingTaskInspector && (millis() - taskInspectorStartTime >= taskInspectorTimeout)) {
    isShowingTaskInspector = false;
    updateDefaultDisplay();
  }

  // Automatic display timeout (except in sub-menus, editor modes, or dialogs)
  if(configIndex == -1 && manualTimeIndex == -1 && confirmTrackingIndex == -1 && 
     !isShowingInfoPage && !isShowingDeleteDialog && !isShowingTaskInspector && 
     (millis() - lastActivityTime > displayTimeout))
  {
    enterLowPowerMode();
  }

  // Handle character selection timeout inside T9 layout engine
  if(configIndex != -1 && currentInput.length() > 0 && (millis() - lastT9Time > t9Timeout) && lastT9Key != '\0') {
    lastT9Key = '\0'; 
    lcd.setCursor(7, 2);
    lcd.print(currentInput + " ");
  }

  // Fills customKeypad.key[] array with up-to 10 active keys. Returns true if there are ANY active keys.
  if(customKeypad.getKeys())
  {
    // Catch the first keystroke event after the display was off / sleep
    if(!isDisplayOn) {
      isDisplayOn = true;
      return;
    }
    resetDisplayTimeout(); 

    // EVALUATE FIRST KEY
    char firstKey = customKeypad.key[0].kchar;
    KeyState firstState = customKeypad.key[0].kstate;

    // Inside Info-Page: Press Enter ('C') or Cancel ('B') to exit
    if (isShowingInfoPage) {
      if (firstState == PRESSED && (firstKey == 'C' || firstKey == 'B')) {
        isShowingInfoPage = false;
        updateDefaultDisplay();
      }
      return;
    }

    if (confirmTrackingIndex != -1) {
      if (firstState == PRESSED) {
        handleConfirmationInput(firstKey);
      }
      return;
    }

    if (isShowingDeleteDialog) {
      if (firstState == PRESSED) {
        handleDeletionInput(firstKey);
      }
      return;
    }
    
    if (configIndex != -1) {
      if (firstState == PRESSED) {
        handleT9Input(firstKey);
      }
      return;
    }

    if (manualTimeIndex != -1) {
      if (firstState == PRESSED) {
        handleManualTimeInput(firstKey);
      }
      return;
    }

    // Check if modifiers are active on the first key position
    if(firstKey == 'S' && (firstState == PRESSED || firstState == HOLD)) {
      isShiftPressed = true;
    }
    else if(firstKey == 'A' && (firstState == PRESSED || firstState == HOLD)) {
      isAPressed = true;
    }
    else if(firstKey == 'B' && (firstState == PRESSED || firstState == HOLD)) {
      isCancelPressed = true;
    }
    else if(firstKey == 'C' && (firstState == PRESSED || firstState == HOLD)) {
      isEnterPressed = true;
    }
    else {
      // Single Key Action (No Shift, No 'A', No 'B', No 'C')
      int taskidx = getKeyIndex(firstKey);
      if(firstState == PRESSED && taskidx != -1) {
        // If inspector is active, a regular press aborts it early
        if (isShowingTaskInspector) isShowingTaskInspector = false;
        handleTracking(taskidx);
      }
    }
    
    // Evaluate multi-key state combos
    if(customKeypad.key[1].kchar != NO_KEY && 
      (customKeypad.key[1].kstate == PRESSED || customKeypad.key[1].kstate == HOLD))
    {
      char secondKey = customKeypad.key[1].kchar;
      int taskidx = getKeyIndex(secondKey);

      // Shift ('S') + Cancel ('B') combo -> Show Info Page
      if(isShiftPressed && secondKey == 'B') {
        isShowingInfoPage = true;
        lcd.clear();
        lcd.setCursor(0, 0); lcd.print("Datapad FW: " + VERSION);
        lcd.setCursor(0, 1); lcd.print("(c) syjnx, 2026");
        if(externalPowerPresent()) {
          lcd.setCursor(0, 2); lcd.print("USB connected");
        }
        else {
          lcd.setCursor(0, 2); lcd.print("Vbat = ");
          lcd.setCursor(7, 2); lcd.print(readBatVoltage(), 3);
          lcd.print("V    ");
        }
        // Print initial time to line 4 immediately
        time_t now = time(nullptr);
        struct tm timeinfo;
        localtime_r(&now, &timeinfo);
        char timeBuf[21];
        strftime(timeBuf, sizeof(timeBuf), "%Y-%m-%d %H:%M:%S", &timeinfo);
        lcd.setCursor(0, 3);
        lcd.print(timeBuf);
        return;
      }

      // Enter ('C') + Task Key combination -> Inspector Mode (Show Multi-line Task Name)
      if(isEnterPressed && taskidx != -1) {
        isShowingTaskInspector = true;
        taskInspectorStartTime = millis();
        showTaskNameMultiLine(taskNames[taskidx]);
        return;
      }

      // Shift + Task Key combination -> Switch into T9 Setup Editor Mode
      if(isShiftPressed && taskidx != -1) {
        configIndex = taskidx;
        currentInput = "";
        lastT9Key = '\0';
        
        lcd.clear();
        lcd.setCursor(0, 0); lcd.print("Enter Jira Task ID");
        lcd.setCursor(0, 1); lcd.print("for Task " + String(taskidx+1));
        lcd.setCursor(0, 2); lcd.print("Entry: ");
        lcd.setCursor(0, 3); lcd.print("Cancel=Del Enter=OK");
        return;
      }

      // Action 'A' + Task Key combination -> Switch into Direct Manual Minute Input Mode
      if(isAPressed && taskidx != -1) {
        // Block manual entry completely if the slot hasn't been configured yet
        if (taskMapping[taskidx] == "*****-*****") {
          lcd.clear();
          lcd.setCursor(0, 1); lcd.print(" No Task programmed ");
          lcd.setCursor(0, 2); lcd.print("  Cannot log time   ");
          delay(1500);
          updateDefaultDisplay();
        } else {
          manualTimeIndex = taskidx;
          currentInput = "";
          
          lcd.clear();
          lcd.setCursor(0, 0); lcd.print("Manual entry for:");
          lcd.setCursor(0, 1); lcd.print(taskMapping[manualTimeIndex]);
          lcd.setCursor(0, 2); lcd.print("Minutes: ");
          lcd.setCursor(0, 3); lcd.print("Cancel=Del Enter=Log");
        }
        return;
      }

      // Cancel ('B') + Task Key combination -> Trigger Slot Deletion Dialog
      if(isCancelPressed && taskidx != -1) {
        if (taskMapping[taskidx] == "*****-*****") {
          // Slot already empty, nothing to do
          lcd.clear();
          lcd.setCursor(0, 1); lcd.print(" Slot already empty ");
          delay(1200);
          updateDefaultDisplay();
        } else {
          deleteIndex = taskidx;
          isShowingDeleteDialog = true;
          
          lcd.clear();
          lcd.setCursor(0, 0); lcd.print("Clear Task " + String(taskidx + 1) + "?");
          lcd.setCursor(0, 1); lcd.print(taskMapping[deleteIndex]);
          lcd.setCursor(0, 2); lcd.print("Reset to empty slot?");
          lcd.setCursor(0, 3); lcd.print("Cancel=No Enter=Yes");

          // Inline-Wait until keys are released
          delay(500);
          while(customKeypad.getKeys()) {
            delay(20);
          }
        }
        return;
      }
    }
  }

  // Refresh interval tick loop for Idle Jira Matrix Grid views (4-second cycle)
  if(activeTimerIndex == -1 && configIndex == -1 && manualTimeIndex == -1 &&
    confirmTrackingIndex == -1 && !isShowingInfoPage && !isShowingDeleteDialog && 
    !isShowingTaskInspector && ((millis() - lastUpdateTime) > 4000))
  {
    lastUpdateTime = millis();
    displayNameToggle = !displayNameToggle;
    updateDefaultDisplay();
  }

  // Live clock update while Info-Page is actively being displayed
  if(isShowingInfoPage) {
    static unsigned long lastInfoClockUpdate = 0;
    if(millis() - lastInfoClockUpdate >= 1000) {
      lastInfoClockUpdate = millis();
      time_t now = time(nullptr);
      struct tm timeinfo;
      localtime_r(&now, &timeinfo);
      char timeBuf[21];
      strftime(timeBuf, sizeof(timeBuf), "%Y-%m-%d %H:%M:%S", &timeinfo);
      lcd.setCursor(0, 3);
      lcd.print(timeBuf);
    }
  }
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

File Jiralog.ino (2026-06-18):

#include <WiFi.h>
#include <HTTPClient.h>
#include <WiFiClientSecure.h>
#include <Keypad.h>
#include <Preferences.h>
#include <LiquidCrystal.h>
#include <ArduinoJson.h>

Preferences preferences;

// HD44780 LCD Pins: LiquidCrystal lcd(rs, en, d4, d5, d6, d7)
LiquidCrystal lcd(9, 46, 8, 16, 15, 7);
const int BACKLIGHT_PIN = 4;

// WLAN and Jira configuration variables
String ssid = "";
String password = "";
String jiraHost = ""; 
String base64Credentials = ""; 

unsigned long lastActivityTime = 0;
const unsigned long displayTimeout = 60000; 
bool isDisplayOn = true;

// Keypad Definition (rows and cols are inverted here to match anti-ghosting diode polarity with library code)
const byte ROWS = 4; 
const byte COLS = 5; 
char hexaKeys[ROWS][COLS] = {
  {'1','5','9','C','G'},
  {'2','6','0','D','H'},
  {'3','7','A','E','I'},
  {'4','8','B','F','K'}
};
byte rowPins[ROWS] = {41, 42, 2, 1}; 
byte colPins[COLS] = {40, 39, 45, 21, 14};

Keypad customKeypad = Keypad(makeKeymap(hexaKeys), rowPins, colPins, ROWS, COLS);

String taskMapping[20];
String taskNames[20];
unsigned long startTimes[20] = {0};
int activeTimerIndex = -1; 

int configIndex = -1;      
int manualTimeIndex = -1;  

String currentInput = "";    
char lastT9Key = '\0';       
int t9CycleIndex = 0;        
unsigned long lastT9Time = 0;
const unsigned long t9Timeout = 1200; 

const String t9Chars[11] = {
  "1", "ABC2", "DEF3", "GHI4", "JKL5", "MNO6", "PQRS7", "TUV8", "WXYZ9", "0 ", "-"
};

int getKeyIndex(char key) {
  if (key >= '1' && key <= '9') return key - '1';
  if (key >= 'A' && key <= 'G') return 9 + (key - 'A');
  if (key >= 'H' && key <= 'K') return 16 + (key - 'H');
  return -1;
}

int getT9LayoutIndex(char key) {
  if (key >= '1' && key <= '9') return key - '1';
  if (key == 'A') return 9;
  if (key == 'B') return 10;
  return -1;
}

void resetDisplayTimeout() {
  lastActivityTime = millis();
  if (!isDisplayOn) {
    digitalWrite(BACKLIGHT_PIN, HIGH); 
    isDisplayOn = true;
    updateDefaultDisplay(); 
  }
}

void updateDefaultDisplay() {
  lcd.clear();
  lcd.setCursor(0, 0);
  lcd.print("   Jira Tracker v1  ");
  lcd.setCursor(0, 1);
  lcd.print("--------------------");
  
  lcd.setCursor(0, 2);
  if (activeTimerIndex != -1) {
    // Zeige den echten Namen an (gekürzt auf 20 Zeichen fürs Display)
    String displayName = taskNames[activeTimerIndex];
    if (displayName.length() == 0 || displayName == "Unbekannter Task") {
      displayName = taskMapping[activeTimerIndex];
    }
    if (displayName.length() > 20) displayName = displayName.substring(0, 17) + "...";
    lcd.print(displayName);
  } else {
    lcd.print("Status: Bereit.");
  }
  
  lcd.setCursor(0, 3);
  lcd.print("Klick=Start Hlt=Zeit");
}

// Liest einen String über die serielle Schnittstelle ein (blockierend fürs Setup)
String readSerialLine() {
  while (!Serial.available()) {
    delay(50);
  }
  String input = Serial.readStringUntil('\n');
  input.trim(); // Zeilenumbrüche und Leerzeichen am Ende entfernen
  return input;
}

void runSerialSetup() {
  lcd.clear();
  lcd.setCursor(0, 0); lcd.print("---- SETUP MODE ----");
  lcd.setCursor(0, 1); lcd.print("Please connect via  ");
  lcd.setCursor(0, 2); lcd.print("serial terminal and ");
  lcd.setCursor(0, 3); lcd.print("use 115200 baud 8N1 ");

  Serial.println("\n==================================================");
  Serial.println("        CONFIGURATION OF TIME TRACKER             ");
  Serial.println("==================================================");
  
  Serial.print("1. Please enter WLAN Name (SSID): ");
  ssid = readSerialLine();
  Serial.println(ssid);

  Serial.print("2. Please enter WLAN Password: ");
  password = readSerialLine();
  Serial.println("********");

  Serial.print("3. Please enter Jira-Host (e.g. company.atlassian.net): ");
  jiraHost = readSerialLine();
  Serial.println(jiraHost);

  Serial.print("4. Please enter Base64 Credentials: ");
  base64Credentials = readSerialLine();
  Serial.println("[SAVED]");

  // Save to Preferences
  preferences.putString("wifi_ssid", ssid);
  preferences.putString("wifi_pass", password);
  preferences.putString("jira_host", jiraHost);
  preferences.putString("jira_cred", base64Credentials);

  Serial.println("\n--> All settings successfully saved! Restarting system...");
  lcd.clear();
  lcd.setCursor(0, 1); lcd.print("Data saved!");
  lcd.setCursor(0, 2); lcd.print("Restarting system...");
  delay(2000);
  ESP.restart();
}

String fetchTaskSummary(String issueKey) {
  if (WiFi.status() != WL_CONNECTED) return "Kein WLAN";
  WiFiClientSecure client;
  client.setInsecure();
  HTTPClient http;
  
  String url = "https://" + jiraHost + "/rest/api/3/issue/" + issueKey + "?fields=summary";
  http.begin(client, url);
  http.addHeader("Authorization", "Basic " + base64Credentials);
  http.addHeader("Accept", "application/json");
  
  int httpCode = http.GET();
  String summary = "Unbekannter Task";
  
  if (httpCode == 200) {
    String payload = http.getString();
    DynamicJsonDocument doc(2048);
    DeserializationError error = deserializeJson(doc, payload);
    if (!error && doc["fields"]["summary"].is<const char*>()) {
      summary = doc["fields"]["summary"].as<String>();
    }
  }
  http.end();
  return summary;
}
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

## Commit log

2026-05-25 initial functionality to log 1h on task NBT-15 on press of a button
2026-05-25 untested: keypad matrix, T9 mode to reassign keys, long-press to directly book time, short-press to start timer
    [Jiralog.ino]
2026-06-04 adjusted pins to board design
2026-06-16 temporary fix of rows and cols of keymatrix
    [Jiralog.ino]
2026-08-13 added configurable maximum timer limit
2026-08-13 added info page and ADC voltage measurements
2026-08-13 tried to optimize the logging to Jira to avoid HTTP -1 and -11 errors
    [timelogger.cpp]
2026-08-13 added two variants of cases
    [Datapad_Case_v1.ipt, Datapad_Case_v1.stl, Datapad_Case_v2.ipt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]
2026-08-13 small fix to wait for WiFi being re-established after a sleep before trying to re-sync with NTP
    [timelogger.cpp]
2026-08-13 next effort to avoid the HTTP -1 error
    [timelogger.cpp]
2026-08-14 added PCB design files
    [Datapad-B_Cu.gbl, Datapad-B_Mask.gbs, Datapad-B_Paste.gbp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]
2026-08-21 added retry mechanism for sending timelogs to Jira API to solve HTTP-1 issue, added proper file header
    [timelogger.cpp]
2026-08-28 fixed bug that led to wrong indication of longer Jira IDs, added some more info to the README
    [timelogger.cpp]

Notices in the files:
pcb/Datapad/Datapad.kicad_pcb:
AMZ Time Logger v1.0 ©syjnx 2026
